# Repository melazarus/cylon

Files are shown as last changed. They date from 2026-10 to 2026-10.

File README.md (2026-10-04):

# Cylon

> A tiny open source / open hardware USB notification light — three side-emitting addressable LEDs on a USB-A stick, driven by a CH32X035 RISC-V MCU.

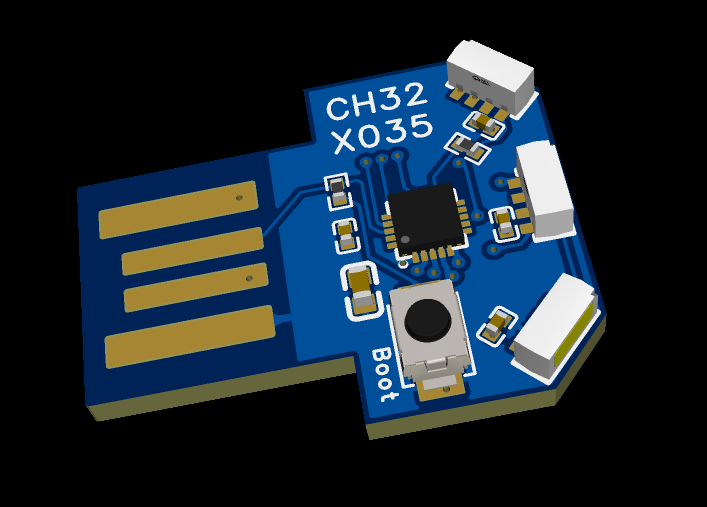
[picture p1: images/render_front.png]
Cylon board render


Cylon plugs straight into a USB-A port and gives you a programmable RGB indicator for build status, notifications, alerts, ambient lighting, etc. It is designed to be cheap, hackable, and easy to manufacture — the USB-A plug is formed by the PCB's own gold-finger edge connector, so there is no connector to solder.

The board speaks class-compliant **USB-MIDI**: the host drives everything with SysEx messages, so no driver is required and any MIDI-capable tool or browser can control it. Firmware can be updated over USB through the factory ROM bootloader.

## Features

- **USB-A PCB plug** — no cable or enclosure required, plugs directly into a host port.
- **CH32X035F8U6** — WCH RISC-V MCU in a small WQFN-20 package, with native USB 2.0 Full-Speed.
- **3× side-emitting WS2812B** (`XL-4020RGBC-2812B`) — individually addressable RGB, arranged so light spills out sideways/around the board. (Note: the mechanical strength of these LEDs is not ideal; a small amount of super glue, or different LEDs, improves it.)
- **USB bootloader + SWD** — flash over USB or via a WCH-LinkE / SWD probe.
- **Boot button** — hold it while plugging in to enter the ROM bootloader; a MIDI command can also reboot into it without touching the board.
- **4 spare GPIOs** — `PA0`–`PA3`, each usable as a push-pull output, a 20 kHz PWM output, or a 50 Hz RC servo output.
- **Minimal BOM** — just 7 components to order, all available from LCSC.
- **Open hardware** — full EasyEDA Pro project, schematic, PCB, Gerbers, and 3D model included.

## Hardware

| | |
|---|---|
| **MCU** | WCH CH32X035F8U6 (RISC-V, WQFN-20) |
| **USB** | USB 2.0 Full-Speed device (USB-A male PCB plug) |
| **LEDs** | 3× XL-4020RGBC-2812B (WS2812B-compatible, side-emitting) |
| **LED data** | `PB1` (`TIM1_CH3N`) → LED1 `DIN`, chained LED1 → LED2 → LED3 |
| **USB D+/D−** | `PC17` (`UDP`) / `PC16` (`UDM`) |
| **Debug** | SWD on `PC18` (`DIO`) / `PC19` (`DCK`) |
| **Boot** | `TS-1088-AR02016` tact switch + 5.1 kΩ resistor to `PC17` |
| **Power** | 5 V from USB, 10 µF bulk + 100 nF decoupling per LED/MCU |
| **Board** | 2-layer, ~23 × 19 mm (incl. USB plug tab), EasyEDA Pro, rev V1.0 |

### Pinout

| Signal | CH32X035 pin |
|---|---|
| WS2812 data out | `PB1` |
| USB `D+` | `PC17` (`UDP`) |
| USB `D−` | `PC16` (`UDM`) |
| SWD `DIO` | `PC18` |
| SWD `DCK` | `PC19` |
| PAD0 | `PA0` |
| PAD1 | `PA1` |
| PAD2 | `PA2` |
| PAD3 | `PA3` |
| `5V0` | `VDD` |
| `GND` | `GND` / EP |

> The WS2812 data line (`PB1`) feeds the first LED through a 100 Ω series resistor; each LED's `DO` feeds the next LED's `DI`, so all three are driven from a single GPIO.

### USB identity

| Field | Value |
|---|---|
| VID / PID | `0x16C0` / `0x27DD` |
| Manufacturer | `AREA3001` |
| Product | `CYLON` |
| Serial | `MD` + 6 hex chars of firmware version + 24 hex chars of the MCU UID |

Every board gets a unique serial number from its 96-bit chip UID; the version prefix also encodes which firmware it is running.

## Protocol

The device is a class-compliant **USB-MIDI** device that listens on **MIDI channel 0**. Control uses **System Exclusive (SysEx)** messages with the tag `13 37`:

```
F0 13 37 <record> ... F7          record = <address> <b1> <b2> <b3>
```

A message may contain any number of 4-byte records; the last write wins. Every payload byte is a **7-bit MIDI data byte** (`0x00`–`0x7F`).

| Address | Target | b1 / b2 / b3 |
| --- | --- | --- |
| `0x00` | all LEDs | r, g, b |
| `0x01`–`0x03` | LED 0/1/2 | r, g, b |
| `0x04`–`0x0A` | animation | base colour (wheels ignore it) |
| `0x0B` | firmware version reply (device → host) | major, minor, patch |
| `0x10`–`0x13` | `PA0`–`PA3` | type, level, speed/ignored |
| `0x7F` | command | cmd, arg0, arg1 |

Unused/reserved addresses are ignored. The full protocol and the memory map live in [`docs/PROTOCOL.md`](docs/PROTOCOL.md).

### Static colours

```
F0 13 37 <led> <r> <g> <b> F7          led = 0x00 (all) or 0x01..0x03
```

`r`/`g`/`b` are 7-bit; the firmware shifts them left by one, so the LED receives an **even** 8-bit value and `0x7F` is the maximum (`0xFE`). Setting a static colour stops any running animation.

### Animations

Addresses `0x04`–`0x0A` start an on-device animation using the same record shape (the three colour bytes are the base colour):

| Address | Animation |
| --- | --- |
| `0x04` | blink at 1 Hz |
| `0x05` | blink at 2 Hz |
| `0x06` | breathe at 1 Hz |
| `0x07` | breathe at 2 Hz |
| `0x08` | Larson scanner (the moving dot) |
| `0x09` | colour wheel, one hue offset per LED |
| `0x0A` | colour wheel, all LEDs the same hue |

Animations are rendered on-device at 50 Hz; the host sends the record once.

### Auxiliary pins

`0x10`–`0x13` map to `PA0`–`PA3` (`TIM2_CH1..CH4`):

| Byte | Meaning |
| ---- | --- |
| `<type>` | `0x00` push-pull output, `0x01` PWM output, `0x02` servo output |
| `<level>` | push-pull: `0x00` low / `0x01` high<br>PWM: `0x00` = 0 % … `0x7F` = 100 % duty<br>servo: `0x00` = 0 % … `0x7F` = 100 % position |
| `<extra>` | push-pull / PWM: ignored<br>servo: move time — `0x00` instant, `0x01`–`0x7F` = 100 ms … 12.7 s |

A pin stays an input until its first record and can switch modes at any time. Pins are independent of the LEDs and do not stop a running animation. PWM runs at 20 kHz; a servo uses a 50 Hz frame with a 0.5–2.5 ms pulse (narrow it with command `0x10` if the servo over-drives) and sweeps to the new position over the move time. Because `PA0`–`PA3` share one timer, PWM reverts to 50 Hz while any servo is active.

### Commands

Address `0x7F` is a command record `<0x7F> <cmd> <arg0> <arg1>`:

| Command | Meaning |
| --- | --- |
| `0x01` | reboot into the ROM USB bootloader |
| `0x02` | request firmware version |
| `0x10` | set the servo pulse range (`arg0` = min, `arg1` = max, 20 µs units) |

Command `0x02` makes the device reply over the USB-MIDI IN endpoint with a normal record:

```
F0 13 37 0B <major> <minor> <patch> F7
```

For firmware `1.0.0` that is `F0 13 37 0B 01 00 00 F7`. Unknown commands and non-zero arguments are ignored.

### Examples

```
LED 0 red              F0 13 37 01 7F 00 00 F7
All LEDs green         F0 13 37 00 00 7F 00 F7
LED0 red, LED2 blue    F0 13 37 01 7F 00 00 03 00 00 7F F7
Larson scanner, cyan   F0 13 37 08 00 7F 7F F7
Colour wheel (offset)  F0 13 37 09 00 00 00 F7
PA0 high               F0 13 37 10 00 01 00 F7
PA1 PWM 50%            F0 13 37 11 01 40 00 F7
PA2 servo 50%, 1 s     F0 13 37 12 02 40 0A F7
Reboot to bootloader   F0 13 37 7F 01 00 00 F7
Request firmware ver.  F0 13 37 7F 02 00 00 F7
```

## Firmware

The PlatformIO project lives in [`firmware/`](firmware), with a small vendored USB-MIDI stack in `firmware/lib/CH32X035_USB_MIDI`.

See [`docs/BUILD.md`](docs/BUILD.md) for the full build, versioning and release process.

| File | Responsibility |
| ---- | --- |
| `main.c` | boot sequence, then `midi_run()` |
| `board.c/.h` | WS2812 driver (`TIM1_CH3N` + DMA1 ch5) and LED state |
| `midi.c/.h` | SysEx parsing, address map, commands |
| `anim.c/.h` | animation engine (free-running `TIM3` time base) |
| `pins.c/.h` | auxiliary `PA0`–`PA3` GPIO / 20 kHz PWM (`TIM2`) |
| `debug.c/.h` | delays and optional `printf` retargeting |

The WS2812 waveform is generated entirely in hardware: **TIM1** runs at 48 MHz with `ARR = 59` (1.25 µs per bit), **DMA1 channel 5** writes one compare value per bit to `TIM1_CH3N`, and the compare value *is* the bit's high time. On boot the firmware starts the LED driver and runs a ~3 s startup colour ramp that ends on LED 0 red, LED 1 green, LED 2 blue; it then brings up USB and enters the MIDI loop.

### Building

Prerequisites: [PlatformIO](https://platformio.org) and the [Community CH32V platform](https://github.com/Community-PIO-CH32V/platform-ch32v).

```bash
pip install platformio
pio pkg install -g -p "https://github.com/Community-PIO-CH32V/platform-ch32v.git#8cf3b51c0ee537756a04c28336f1466e03424020"

cd firmware
pio run -e release      # optimised, no logging
pio run -e debug        # -Og -g3 with serial logging on USART1 (PB10, 115200)
```

The platform is pinned to a commit so builds are reproducible. The output binary is `firmware/.pio/build/<env>/firmware.bin`. The firmware version comes from the `CYLON_VERSION` environment variable (e.g. a tag `v1.0.0`) and falls back to `1.0.0`; it is reported over USB-MIDI (command `0x02`) and encoded in the USB serial number.

### Flashing

`firmware/platformio.ini` sets `upload_protocol = isp`, so PlatformIO uses its bundled [`wchisp`](https://github.com/ch32-rs/wchisp):

```bash
cd firmware
pio run -e release -t upload
```

Put the board into the ROM bootloader first — **unplug USB, hold BOOT, plug USB back in**. The BOOT button pulls `PC17` (the boot-detection pin, which doubles as USB `D+`) high at power-up; the pin is sampled only once, on reset. The bootloader enumerates as a WCH ISP device (`4348:55e0` / `1a86:55e0`).

You can skip the button by asking a running board to reboot into the bootloader over MIDI:

```bash
uv run tools/set_leds.py --boot
cd firmware && pio run -e release -t upload
```

SWD (`PC18`/`PC19`) is the button-free alternative and does not depend on the boot strap. On Windows you may need to bind the bootloader to WinUSB with [Zadig](https://zadig.akeo.ie/). On Linux, grant access with a udev rule and reload it:

```
# /etc/udev/rules.d/60-wchisp.rules
SUBSYSTEM=="usb", ATTR{idVendor}=="4348", ATTR{idProduct}=="55e0", MODE="0666"
SUBSYSTEM=="usb", ATTR{idVendor}=="1a86", ATTR{idProduct}=="55e0", MODE="0666"
```

```bash
sudo udevadm control --reload-rules && sudo udevadm trigger
# replug the board and restart the browser
```

### Releases

Pushing a `v<major>.<minor>.<patch>` tag runs [`.github/workflows/release.yml`](.github/workflows/release.yml): it builds the `release` environment with `CYLON_VERSION` set from the tag and attaches `firmware.bin` and `cylon-<tag>.bin` to a **draft** GitHub release. Publish the draft to make the version available to the web tool's updater.

## Web control & firmware update

[`public/`](public) is a responsive static page (published to GitHub Pages) for controlling the board from a Chromium browser:

- LED colours and animations, the four I/O pins, and the live firmware version;
- firmware updates over USB — it lists versions from this repository's GitHub releases, can reboot the board into the bootloader, and flashes over WebUSB.

It uses **Web MIDI** for control and **WebUSB** for flashing, so it needs Chrome or Edge (desktop or Android) over HTTPS. Once deployed it is at `https://melazarus.github.io/cylon/`; the Pages workflow is [`.github/workflows/pages.yml`](.github/workflows/pages.yml) and the repository's Pages source must be set to **GitHub Actions**.

## Command-line tool

[`tools/set_leds.py`](tools/set_leds.py) is a [uv](https://docs.astral.sh/uv/) / PEP 723 script (it pulls in `pygame` for its MIDI backend):

```bash
uv run tools/set_leds.py 0 ff0000     # LED 0 red
uv run tools/set_leds.py all ffffff   # all LEDs white
uv run tools/set_leds.py 0 red        # named colours
uv run tools/set_leds.py --pin 1 --pwm 64                 # PA1 PWM, 50 %
uv run tools/set_leds.py --pin 2 --servo 64 --speed 10    # PA2 servo 50 %, 1 s move
uv run tools/set_leds.py --servo-range 500 2260           # narrow the servo pulse range
uv run tools/set_leds.py --list       # list MIDI output ports
uv run tools/set_leds.py --boot       # reboot into the ROM bootloader
uv run tools/set_leds.py --version    # read the firmware version
```

Named colours: `off`, `black`, `red`, `green`, `blue`, `white`, `yellow`, `cyan`, `magenta`, `orange`, `purple`, `pink`. The port is auto-detected by matching `"cylon"`; use `--port` if your system names it differently.

## Repository layout

```
.
├── .github/workflows/        # GitHub Pages deploy + tagged firmware releases
├── docs/
│   ├── BUILD.md              # build, versioning & release guide
│   └── PROTOCOL.md           # USB-MIDI protocol reference
├── firmware/                 # PlatformIO firmware (CH32X035) + version.py
├── hardware/                 # EasyEDA Pro project, schematic, PCB, gerbers, BOM, 3D
├── images/
│   └── render_front.png      # Board render
├── public/                   # Static web tool (deployed to GitHub Pages)
├── tools/                    # Python CLI
├── LICENSE
└── README.md
```

## Contributing

Issues, pull requests, and hardware/firmware forks are all welcome. If you build one, share a photo!

## License

Released under the [MIT License](LICENSE). © 2026 Hans Polders.

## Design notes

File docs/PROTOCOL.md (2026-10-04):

# Cylon — protocol & memory map

Reference for the wire protocol and the CH32X035 memory layout used by the
firmware. Source of truth is the code: `firmware/src/midi.c` (protocol),
`board.c`, `anim.c`, `pins.c`, and the PlatformIO SDK headers for the addresses.

---

# Part 1 — USB-MIDI protocol

## 1.1 Transport

- Class-compliant **USB-MIDI** device (no host driver).
- The device listens on **MIDI channel 0** only.
- The device also has a **USB-MIDI IN** endpoint. Command replies (currently
  only the firmware version) are sent back as SysEx, so a host that wants a
  reply must open the matching MIDI input as well as the output.
- **System Exclusive (SysEx)** — full control: static colours, animations,
  auxiliary pins, commands.
- Every byte in a SysEx payload is a **7-bit MIDI data byte** (`0x00`–`0x7F`).

## 1.2 SysEx framing

```
F0 13 37 [ <record> ] ... F7
```

| Byte | Meaning |
| ---- | --- |
| `F0` | SysEx start |
| `13 37` | protocol tag (a chosen marker, **not** a registered manufacturer ID) |
| records | one or more 4-byte records (below) |
| `F7` | SysEx end |

A single message may carry any number of records; they are applied in order and
the last write wins. The parser also accepts a message split across several
USB-MIDI packets and all four SysEx Code Index Numbers (`0x04`–`0x07`).

## 1.3 Records and the address map

Each record is `<address> <b1> <b2> <b3>` — four 7-bit bytes. The first byte
selects what the record does:

| Address | Target | b1 | b2 | b3 |
| --- | --- | -- | -- | -- |
| `0x00` | all LEDs | r | g | b |
| `0x01`–`0x03` | LED 0/1/2 | r | g | b |
| `0x04`–`0x0A` | animation | see §1.5 | | |
| `0x0B` | firmware version reply (device → host) | major | minor | patch |
| `0x0C`–`0x0F` | *reserved* | | | |
| `0x10`–`0x13` | pin PA0–PA3 | type | level | speed / ignored |
| `0x14`–`0x7E` | *reserved* | | | |
| `0x7F` | command | cmd | arg0 | arg1 |

Unused/reserved addresses are ignored.

## 1.4 Static LED colour

```
<led> <r> <g> <b>          led = 0x00 (all) or 0x01..0x03
```

`r`/`g`/`b` are 7-bit; the firmware shifts them left by one, so the LED receives
an **even** 8-bit value and `0x7F` is the maximum (`0xFE`). Setting a static
colour **stops any running animation**.

## 1.5 Animations

Addresses `0x04`–`0x0A` start an animation. The three colour bytes are the base
colour for the first four and the scanner; the colour wheels ignore them.

| Address | Animation | Colour bytes |
| --- | --- | --- |
| `0x04` | blink at 1 Hz | base colour |
| `0x05` | blink at 2 Hz | base colour |
| `0x06` | breathe at 1 Hz | base colour |
| `0x07` | breathe at 2 Hz | base colour |
| `0x08` | Larson scanner (the moving dot) | base colour |
| `0x09` | colour wheel, one hue offset per LED | ignored |
| `0x0A` | colour wheel, all LEDs same hue | ignored |

Animations are rendered on-device at 50 Hz. Any static colour record (§1.4) stops the running animation.

## 1.6 Auxiliary pins

Addresses `0x10`–`0x13` map to **PA0–PA3**:

| Byte | Meaning |
| ---- | --- |
| `<type>` | `0x00` push-pull output, `0x01` PWM output, `0x02` servo output |
| `<level>` | push-pull: `0x00` low / `0x01` high<br>PWM: `0x00` = 0 % … `0x7F` = 100 % duty<br>servo: `0x00` = 0 % … `0x7F` = 100 % position |
| `<extra>` | push-pull / PWM: ignored<br>servo: move time — `0x00` = instant, `0x01`–`0x7F` = 100 ms … 12.7 s |

A pin stays an input until its first record and can switch between modes at any
time. Pins are independent of the LEDs and do **not** stop a running animation.

- **PWM** runs at 20 kHz.
- **Servo** drives a standard RC servo: a 50 Hz frame with a 0.5 ms (0 %) to
  2.5 ms (100 %) pulse (configurable with command `0x10`). A non-zero move time
  sweeps the position linearly from where it is now to the new target.
- PA0–PA3 are the four channels of **one timer** (`TIM2`), so PWM (20 kHz) and
  servo (50 Hz) cannot run at once: while at least one servo is active the
  timer runs at 50 Hz and any PWM pin is also 50 Hz (its duty is unchanged).

## 1.7 Commands

Address `0x7F` is a command record `<0x7F> <cmd> <arg0> <arg1>`:

| Command | Meaning | 
| --- | --- |
| `0x01` | reboot into the ROM USB bootloader |
| `0x02` | request firmware version (reply: record `0x0B`) |
| `0x10` | set the servo pulse range (`arg0` = min, `arg1` = max, 20 µs units) |

Unknown commands and non-zero arguments are ignored.

Command `0x02` asks the device to answer over the USB-MIDI IN endpoint with a
normal four-byte record so the host can reuse its record parser:

```
F0 13 37 0B <major> <minor> <patch> F7
```

Each component is a 7-bit number. The current firmware is `1.0.0`, so the
reply is `F0 13 37 0B 01 00 00 F7`. The device answers once per matching `0x02`
record; `arg0` and `arg1` must be zero, like every other command.

Command `0x10` sets the pulse range used by servo pins (type `0x02`). Both
arguments are in **20 µs units** (`0x00`–`0x7F` = 0–2540 µs); the default is
`0x19` (25 → 500 µs) to `0x7D` (125 → 2500 µs). Narrow it if a servo reaches
its mechanical limit before 100 %: a servo that buzzes above ≈2.26 ms can be
limited to `F0 13 37 7F 10 19 71 F7` (500–2260 µs), after which position `0x7F`
is that maximum instead of over-driving the servo. The setting is runtime only
and applies to every servo pin.

## 1.8 Interaction rules

- A **static colour** (SysEx `0x00`–`0x03`) **stops** any running
  animation and holds that colour.
- An **animation** starts (or replaces) the running animation.
- **Pins** never affect the LEDs and never stop an animation.

## 1.9 Examples

```
LED 0 red              F0 13 37 01 7F 00 00 F7
All LEDs green         F0 13 37 00 00 7F 00 F7
LED0 red, LED2 blue    F0 13 37 01 7F 00 00 03 00 00 7F F7
Larson scanner, cyan   F0 13 37 08 00 7F 7F F7
Colour wheel (offset)  F0 13 37 09 00 00 00 F7
PA0 high               F0 13 37 10 00 01 00 F7
PA1 PWM 50%            F0 13 37 11 01 40 00 F7
PA2 servo 50%, 1 s     F0 13 37 12 02 40 0A F7
Reboot to bootloader   F0 13 37 7F 01 00 00 F7
Request firmware ver.  F0 13 37 7F 02 00 00 F7
Version reply (1.0.0)  F0 13 37 0B 01 00 00 F7   (device → host)
```

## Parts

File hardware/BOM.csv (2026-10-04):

No. | Quantity | Comment | Designator | Footprint | Value | Manufacturer Part | Manufacturer | Supplier Part | Supplier
1 | 1 | TS-1088-AR02016 | Boot | SW-SMD_L3.9-W3.0-P4.45 |  | TS-1088-AR02016 | XUNPU(讯普) | C720477 | LCSC
2 | 4 | 100nF | C1,C2,C3,C4 | C0402 | 100nF | CL05B104KO5NNNC | SAMSUNG(三星) | C1525 | LCSC
3 | 1 | 10uF | C5 | C0603 | 10uF | CL10A106KP8NNNC | SAMSUNG(三星) | C19702 | LCSC
4 | 3 | XL-4020RGBC-2812B | LED1,LED2,LED3 | LED-SMD_4P-L4.0-W1.7_XL-4020RGBC-WS2812B |  | XL-4020RGBC-2812B | XINGLIGHT(成兴光) | C3647024 | LCSC
5 | 1 | 5.1kΩ | R1 | R0402 | 5.1kΩ | FRC0402J512 TS | FOJAN(富捷) | C2906948 | LCSC
6 | 1 | 100Ω | R2 | R0402 | 100Ω | 0402WGF1000TCE | UNI-ROYAL(厚声) | C25076 | LCSC
7 | 1 | USB-A-PCB | U1 | USB-A-PCB
8 | 1 | CH32X035F8U6 | U2 | WQFN-20_L3.0-W3.0-P0.40-TL-EP1.7 |  | CH32X035F8U6 | WCH(南京沁恒) | C42442062 | LCSC

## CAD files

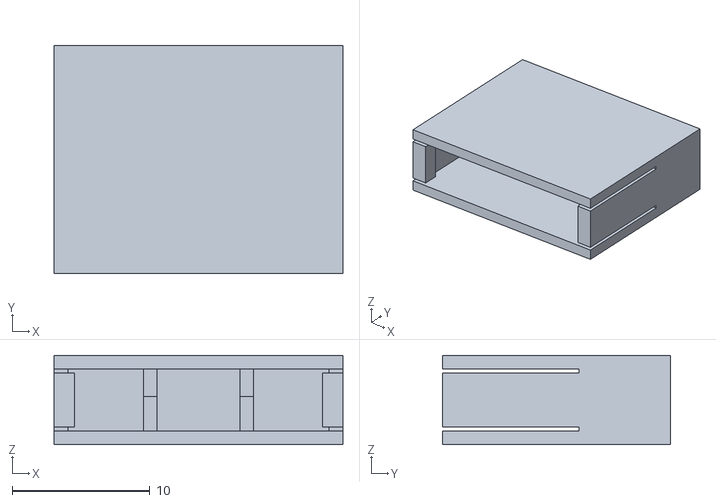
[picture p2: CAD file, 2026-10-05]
case/cover.stl
21.0 x 16.6 x 6.50

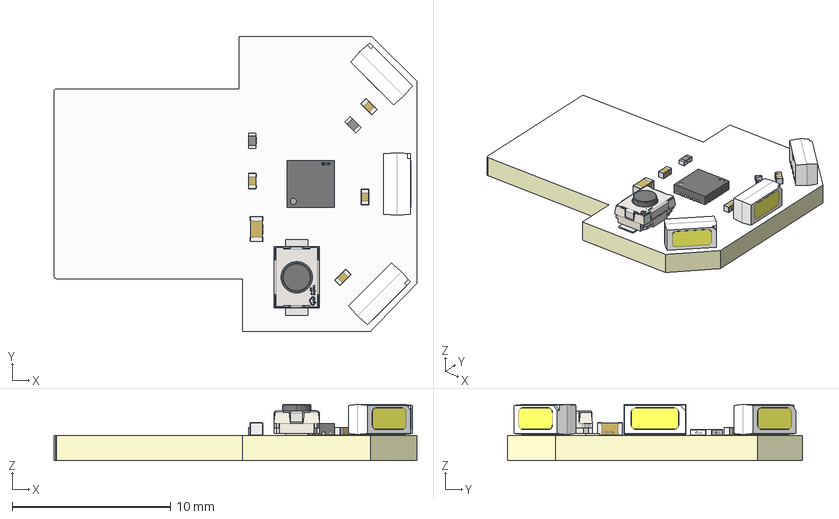
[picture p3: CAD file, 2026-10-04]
hardware/3D.step
23.0 x 18.6 x 3.55 mm
Board~OXDE
TopCopper~OXDE
BottomCopper~OXDE
TopSilkscreen~OXDE
BottomSilkscreen~OXDE
TopFpcStiffener~OXDE
BottomFpcStiffener~OXDE
C0402~C0402_L1.0-W0.5-H0.5~OXDE x 4
R0402~R0402_L1.0-W0.5-H0.4~OXDE x 2
C0603~C0603_L1.6-W0.8-H0.8~OXDE
SW-SMD_L3.9-W3.0-P4.45~SW-SMD_L3.9-W2.9-H2.0-LS4.8~OXDE
LED-SMD_4P-L4.0-W1.7_XL-4020RGBC-WS2812B~LED-SMD_4P-L4.0-W1.7_ XL-4020RGBC-WS2812B~OXDE x 3
WQFN-20_L3.0-W3.0-P0.40-TL-EP1.7~WQFN-20_ L3.0-W3.0-H0.8-P0.40-TL-EP1.7~OXDE

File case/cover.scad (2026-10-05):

/* Cylon cover — slide-on shell for the board.
 *
 * The board enters from the open front (Y = 0) and butts against the back
 * wall. Two shallow grooves at the top and bottom of the cavity act as
 * retention lips, and the small posts at the front corners locate the board.
 *
 * Everything below is parametric; the defaults reproduce the original part.
 * Dimensions are in millimetres. Each parameter group has a section comment so
 * it shows up grouped in OpenSCAD's Customizer.
 */

/* [Board] */
board_w   = 19;    // board width (X)
board_d   = 16;    // board depth that slides into the cover (Y)
board_h   = 4.5;   // board + tallest component (Z)

/* [Shell] */
wall      = 1;     // side, floor and roof thickness
back_wall = 0.6;   // material left behind the board

/* [Retention grooves] */
groove_h     = 0.3; // groove height (Z)
groove_inset = 6;   // how far the groove stops short of the back (Y)
cut          = 0.05; // overcut so the groove clears the side walls

/* [Back clips] */
clip_w     = 1;    // clip width (X)
clip_d     = 4;    // clip depth (Y)
clip_inset = 4;    // clip front face offset from the outer back (Y)
tab_h      = 3.5;  // short tab height (Z)
tab_d      = 6;    // short tab depth (Y)

/* [Front posts] */
post   = 1.5;         // post cross-section (X/Y)
post_h = 3.9;         // post height (Z)
post_z = wall + 0.3;  // post base height (Z)

/* [Hidden] */
outer_w = board_w + 2 * wall;  // overall width
outer_d = board_d + back_wall; // overall depth
outer_h = board_h + 2 * wall;  // overall height

// --------------------------------------------------------------- modules

// Hollow shell: open at the front, closed at the back, with both grooves.
module shell() {
    difference() {
        cube([outer_w, outer_d, outer_h]);

        // board cavity (the extra `cut` keeps the back wall exactly back_wall deep)
        translate([wall, -cut, wall])
            cube([board_w, board_d + cut, board_h]);

        // retention grooves at the floor and roof of the cavity
        for (z = [wall, wall + board_h - groove_h])
            translate([-cut, -cut, z])
                cube([outer_w + 2 * cut, board_d - groove_inset, groove_h]);
    }
}

// Back clips: two full-height clips plus two shorter locating tabs.
module clips() {
    for (x = [outer_w / 3, outer_w * 2 / 3]) {
        translate([x - clip_w / 2, outer_d - clip_inset, 0])
            cube([clip_w, clip_d, outer_h]);
        translate([x - clip_w / 2, outer_d - tab_d, 0])
            cube([clip_w, tab_d, tab_h]);
    }
}

// Front corner posts that locate the board.
module posts() {
    for (x = [0, outer_w - post])
        translate([x, 0, post_z])
            cube([post, post, post_h]);
}

// --------------------------------------------------------------- assembly

union() {
    shell();
    clips();
    posts();
}

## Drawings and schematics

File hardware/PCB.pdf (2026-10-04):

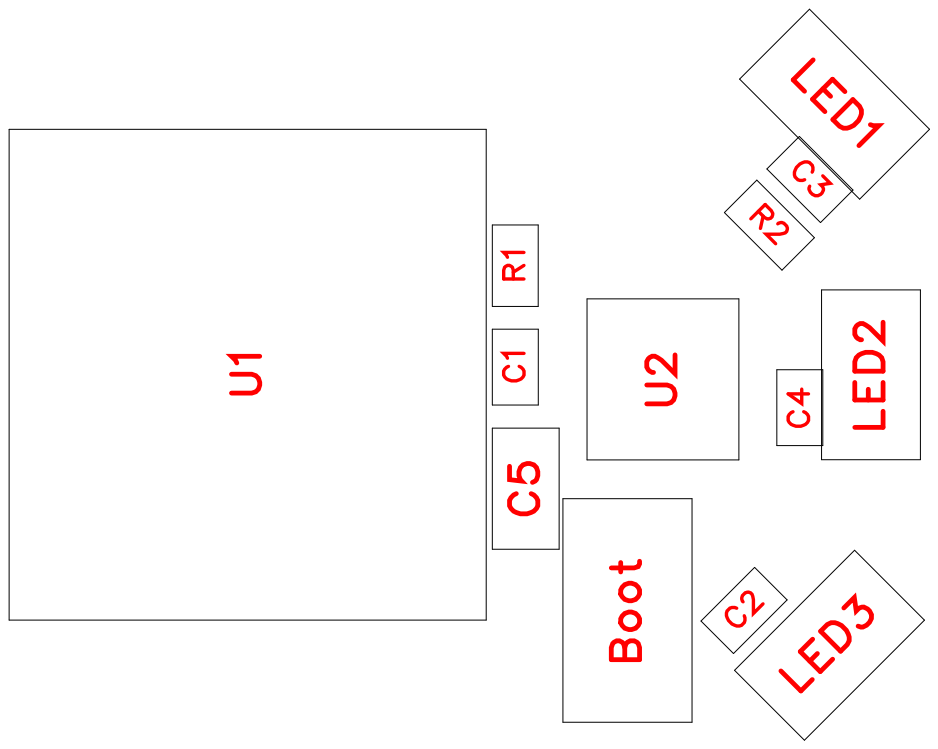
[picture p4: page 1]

No. | Quantity | Comment | Designator | Footprint | Value | Manufacturer Part | Manufacturer | Supplier Part | Supplier
1 | 1 | TS-1088-AR 02016 | Boot | SW-SMD_L3 .9-W3.0-P4.4 5 | | TS-1088-AR 02016 | XUNPU(讯普 ) | C720477 | LCSC
2 | 4 | 100nF | C1,C2,C3,C4 | C0402 | 100nF | CL05B104K O5NNNC | SAMSUNG( ) 三星 | C1525 | LCSC
3 | 1 | 10uF | C5 | C0603 | 10uF | CL10A106KP 8NNNC | SAMSUNG( ) 三星 | C19702 | LCSC
4 | 3 | XL-4020RGB C-2812B | LED1,LED2,LED3 | LED-SMD_4 P-L4.0-W1.7 _XL-4020RG BC-WS2812 B | | XL-4020RGB C-2812B | XINGLIGHT( 成兴光 ) | C3647024 | LCSC
5 | 1 | 5.1k | R1 | R0402 | 5.1k | FRC0402J51 2 TS | FOJAN(富捷 ) | C2906948 | LCSC
6 | 1 | 100 | R2 | R0402 | 100 | 0402WGF10 00TCE | UNI-ROYAL( 厚声 ) | C25076 | LCSC
7 | 1 | USB-A-PCB | U1 | USB-A-PCB
8 | 1 | CH32X035F8 U6 | U2 | WQFN-20_L 3.0-W3.0-P0. 40-TL-EP1.7 | | CH32X035F8 U6 | WCH(南京沁 恒) | C42442062 | LCSC

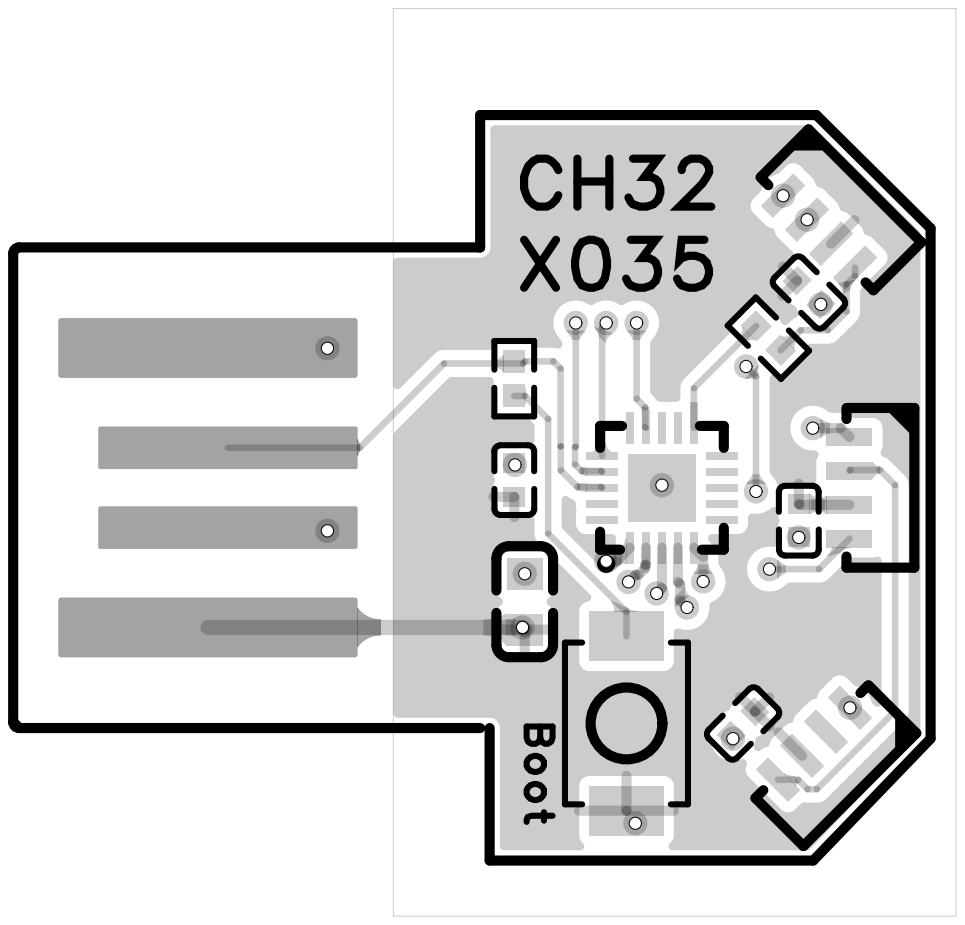
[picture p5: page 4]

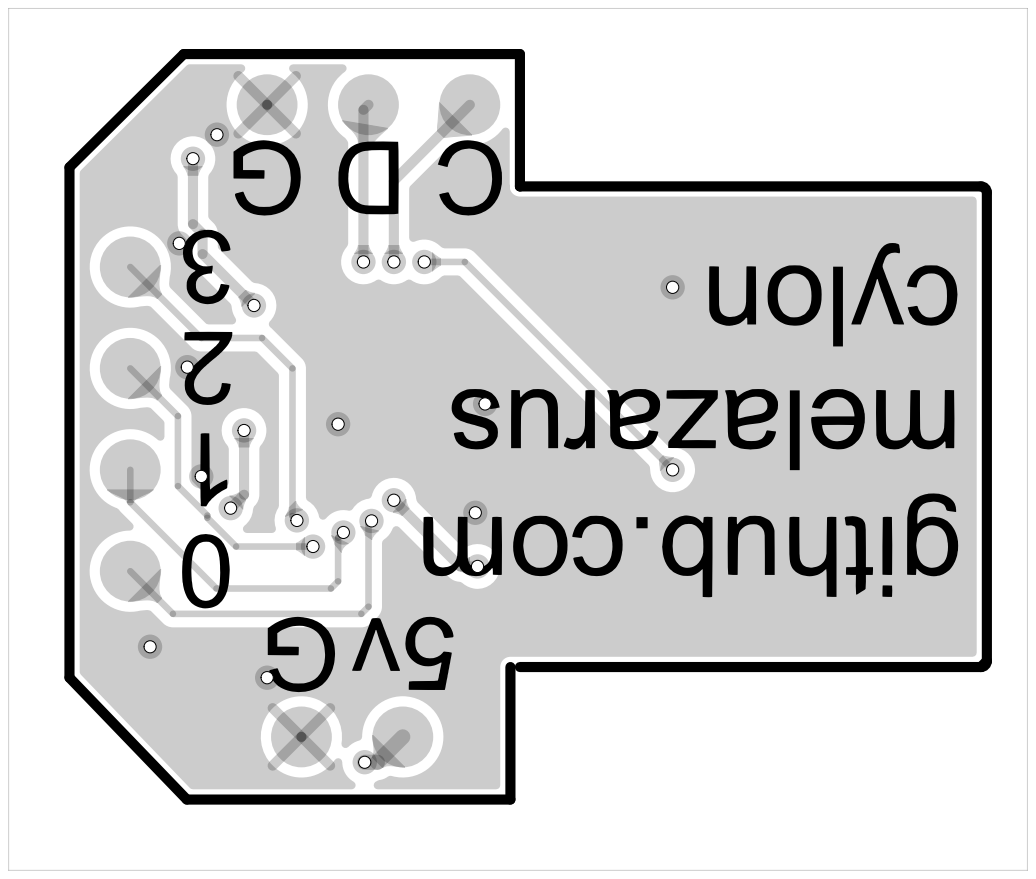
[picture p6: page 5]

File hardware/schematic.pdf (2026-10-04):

Power | MCU - CH32X035

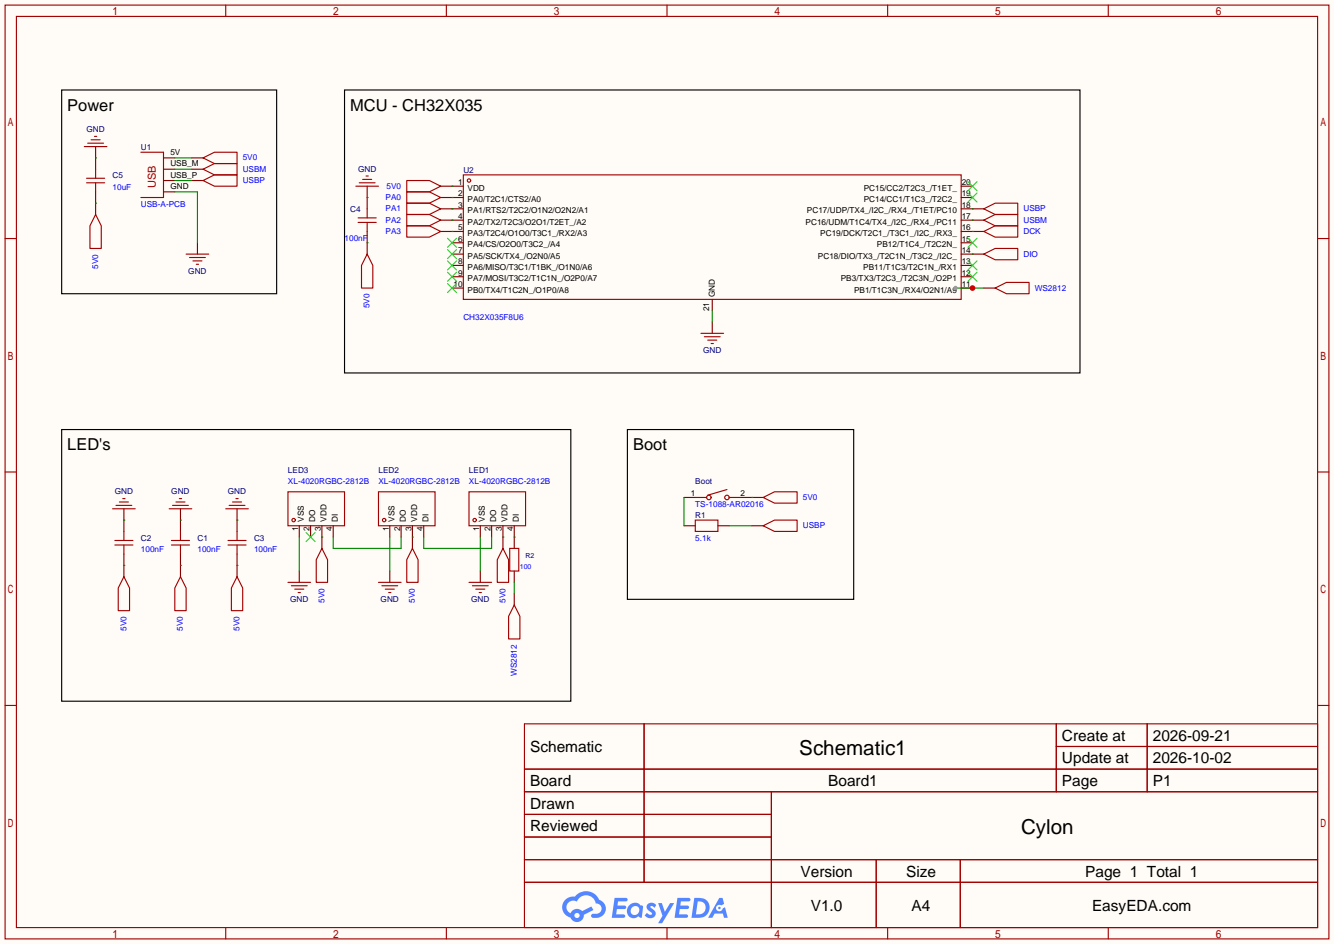
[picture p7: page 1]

Schematic | Schematic1 | Create at | 2026-09-21

Update at | 2026-10-02

Board | Board1 | Page | P1
Drawn | | Cylon
Reviewed

Version | Size | Page 1 Total 1
V1.0 | A4 | EasyEDA.com

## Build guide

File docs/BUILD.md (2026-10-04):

# Building, versioning & releasing

How to build the Cylon firmware, choose a version number, and cut a release.
The wire protocol is documented separately in [`PROTOCOL.md`](PROTOCOL.md).

## Lifecycle at a glance

```
local   pio run -e release         -> firmware/.pio/build/release/firmware.bin
tag     git tag v1.1.0 && push     -> .github/workflows/release.yml
CI      build with CYLON_VERSION   -> draft release: firmware.bin, cylon-v1.1.0.bin
publish click "Publish release"    -> .github/workflows/pages.yml bundles the binary
site    version selector           -> WebUSB flash
```

## Prerequisites

- [PlatformIO](https://platformio.org) (the CLI is enough)
- The [Community CH32V platform](https://github.com/Community-PIO-CH32V/platform-ch32v), pinned to a known commit:

```bash
pip install platformio
pio pkg install -g -p "https://github.com/Community-PIO-CH32V/platform-ch32v.git#8cf3b51c0ee537756a04c28336f1466e03424020"
```

The pin (also used by the release workflow) makes builds reproducible. The first
build downloads the WCH none-OS SDK and the RISC-V toolchain, so it takes a
while; later builds are fast.

## Environments

`firmware/platformio.ini` defines two environments:

| Environment | Flags | Notes |
| --- | ----- | ----- |
| `debug` | `-DDEBUG=1 -Og -g3 -Wall -Wextra` | serial logging on `USART1` (`PB10`, 115200 8N1) |
| `release` | `-DDEBUG=0 -Os -Wall -Wextra` | drops logging and newlib `printf`; the environment CI builds |

Both must build **warning-free**. The output is
`firmware/.pio/build/<env>/firmware.bin`.

## The firmware version

The version is injected at build time by [`firmware/version.py`](../firmware/version.py)
(a PlatformIO pre-script):

- It reads **`CYLON_VERSION`** from the environment (the release workflow passes
  the git tag, e.g. `v1.1.0`).
- If unset, it falls back to **`DEFAULT_VERSION`** (`1.0.0`).
- It accepts `v<major>.<minor>.<patch>` (the `v` is optional). Anything that
  isn't semver prints a warning and falls back to the default.
- It defines the `VERSION_MAJOR` / `VERSION_MINOR` / `VERSION_PATCH` macros used
  by the USB-MIDI library (USB serial number) and by `midi.c` (the `0x02`
  version reply).

Bump `DEFAULT_VERSION` when you release, so a plain local build reports the same
version as the release. CI overrides it from the tag, so the tag is the single
source of truth for released firmware.

```bash
# local build reporting a specific version
CYLON_VERSION=v1.1.0 pio run -e release
```

### Where the version appears

| Place | Format | Example for `1.1.0` |
| ----- | --- | --- |
| USB serial number | `MD` + 6 hex chars + 24 hex UID | `MD010100…` |
| USB-MIDI `0x02` reply (record `0x0B`) | `F0 13 37 0B <major> <minor> <patch> F7` | `F0 13 37 0B 01 01 00 F7` |
| Release asset | `cylon-<tag>.bin` | `cylon-v1.1.0.bin` |

## Building

```bash
cd firmware
pio run -e release      # or: pio run -e debug
```

## Flashing

See the README's [Flashing](../README.md#flashing) section for the full detail.
In short:

- **USB ISP (normal):** put the board in the ROM bootloader — unplug USB, hold
  BOOT, plug back in — then `pio run -e release -t upload`. The bootloader
  enumerates as `4348:55e0` / `1a86:55e0`.
- **Without the button:** `uv run tools/set_leds.py --boot` (or the web tool's
  checkbox) reboots a running board into the bootloader over MIDI.
- **SWD:** `PC18`/`PC19` via a WCH-LinkE, always available and independent of
  the boot strap.
- **Browser:** the `public/` web tool flashes over WebUSB. On Windows bind the
  bootloader to WinUSB with [Zadig](https://zadig.akeo.ie/); on Linux add the
  udev rule (see the README).

## Versioning

Cylon follows [Semantic Versioning](https://semver.org/): `MAJOR.MINOR.PATCH`.

| Change | Bump | Example |
| --- | ---- | --- |
| **New, backwards-compatible feature** | **MINOR** | `1.0.0 → 1.1.0` — a new animation, command, pin mode |
| **Bug fix only** (no new functionality) | **PATCH** | `1.0.0 → 1.0.1` — fix flicker, correct a colour |
| **Breaking change** to the protocol or behaviour | **MAJOR** | `1.0.0 → 2.0.0` — change an existing record's meaning, remove an address |

Rules of thumb:

- Adding a new command or a new address/record is **MINOR** — existing tools
  keep working.
- Changing what an existing address or command *does*, or removing one, is
  **MAJOR**.
- If a change touches the protocol, update [`PROTOCOL.md`](PROTOCOL.md) in the
  same commit and mention it in the release notes.

## Cutting a release

1. (Optional but tidy) bump `DEFAULT_VERSION` in `firmware/version.py` to the
   new version.
2. Commit and push to `main`.
3. Tag and push:

   ```bash
   git tag -a v1.1.0 -m "Cylon 1.1.0"
   git push origin v1.1.0
   ```

4. [`.github/workflows/release.yml`](../.github/workflows/release.yml) runs:
   installs PlatformIO + the pinned CH32V platform, builds the `release`
   environment with `CYLON_VERSION` set from the tag, and creates a **draft**
   GitHub release with `firmware.bin` and `cylon-<tag>.bin`.
5. Review and **Publish** the draft. Publishing triggers
   [`.github/workflows/pages.yml`](../.github/workflows/pages.yml), which runs
   [`.github/scripts/bundle_firmware.py`](../.github/scripts/bundle_firmware.py)
   to download published release binaries into `public/firmware/` and writes
   `releases.json`; the site's version selector then lists the new version.

Notes:

- Releases are created as **drafts** on purpose — nothing is public (and the
  web updater won't list it) until you publish.
- To re-run a build for the same tag, delete the tag and draft, then re-push:

  ```bash
  git tag -d v1.1.0
  git push origin :refs/tags/v1.1.0
  git tag -a v1.1.0 -m "Cylon 1.1.0"
  git push origin v1.1.0
  ```

- The site serves firmware **same-origin** from `public/firmware/` because
  GitHub's release asset host does not send CORS headers. Don't link the site
  directly at `github.com/…/releases/download/…`.

## Troubleshooting

- **Both environments must build warning-free** (`-Wall -Wextra`); treat warnings
  as errors.
- **Version looks wrong:** check the `Cylon firmware version X.Y.Z` line the
  pre-script prints at the top of the build, and remember a plain local build
  uses `DEFAULT_VERSION`, not the latest tag.
- **Flashed but still the old version:** the board's `0x02` reply and USB serial
  report the *built* version — re-run with the right `CYLON_VERSION`/tag.
- **Firmware update fails:** the device may be left in the bootloader; unplug
  and replug to run the application again, then reflash. A bad flash is always
  recoverable via the BOOT strap or SWD.

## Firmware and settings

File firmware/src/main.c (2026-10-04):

#include <ch32x035.h> /* both X033 and X035 */

#include <wch_usbmidi_internal.h>

#include "anim.h"
#include "board.h"
#include "debug.h"
#include "midi.h"

int main(void)
{
    SystemInit();
#ifdef NVIC_PriorityGroup_2
    NVIC_PriorityGroupConfig(NVIC_PriorityGroup_2);
#else
    NVIC_PriorityGroupConfig(NVIC_PriorityGroup_1);
#endif
    SystemCoreClockUpdate();
    Delay_Init();

#if DEBUG
    /* serial logging for the debug build (USART1 TX = PB10, 115200 8N1) */
    USART_Printf_Init(115200);
#endif

    /* bring up the LED driver and hold the data line low right away; the LEDs
     * show an undefined color until they receive their first valid frame */
    board_init();
    anim_init();

    PRINT("SystemClk: %u\r\n", (unsigned)SystemCoreClock);
    PRINT("ChipID: %08x\r\n", (unsigned)DBGMCU_GetCHIPID());

    
    /* Startup animation, will change in the future when there is a state we can persist.
     */
    for (int i = 0; i < 30; i++)
    {
        board_set_led(0, i*8, 0x00, (29*8)-(i*8));
        board_set_led(1, (29*8)-(i*8), i*8, 0x00);
        board_set_led(2, 0x00, (29*8)-(i*8), i*8);

        board_show_leds();
        Delay_Ms(100);
    }

    USB_init();

    PRINT("Cylon init done\r\n");

    /* USB-MIDI LED controller mode, never returns */
    midi_run();
}

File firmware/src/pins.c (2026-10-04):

/* Auxiliary GPIO / PWM / servo outputs PA0..PA3 for SysEx addresses 0x10..0x13.
 *
 * Type 0x00 drives the pin as a plain push-pull GPIO (level 0 = low, 1 = high).
 * Type 0x01 switches the pin to PWM and uses level as a duty cycle from 0x00
 * (0%) to 0x7F (100%). Type 0x02 drives an RC servo: level is the position
 * (0x00..0x7F = 0..100%) and the extra byte is the move time (0x00 = instant,
 * 0x01..0x7F = 100 ms .. 12.7 s).
 *
 * PA0..PA3 are TIM2_CH1..CH4 and share a single time base. PWM wants 20 kHz,
 * a servo wants a 0.5..2.5 ms pulse every 20 ms (50 Hz), so the timer is
 * reconfigured whenever the active modes change: it runs at 20 kHz while only
 * GPIO/PWM pins are in use and at 50 Hz as soon as one servo is active. A PWM
 * record applied while a servo is active is still honoured as a duty
 * percentage, but at 50 Hz.
 *
 * Servo moves are interpolated in pins_tick() from the millisecond clock in
 * anim.c, so a move time produces a smooth sweep rather than a jump.
 */
#include <ch32x035.h>

#include "anim.h"
#include "pins.h"

#define PWM_PERIOD    (2399u)  /* 48 MHz / 2400 = 20 kHz */
#define SERVO_PSC     (47u)    /* 48 MHz / 48 = 1 MHz, so 1 tick = 1 us */
#define SERVO_PERIOD  (19999u) /* 20000 us = 20 ms = 50 Hz */
#define LEVEL_MAX     (0x7Fu)  /* 7-bit level: 0x00..0x7F = 0..100% */

/* Servo pulse range, configurable through pins_set_servo_range(). Values are
 * in 20 us units so 0.5..2.5 ms fits in a 7-bit byte. */
#define SERVO_RANGE_STEP_US   (20u)
#define SERVO_RANGE_MIN_UNITS (25u)  /* 500 us */
#define SERVO_RANGE_MAX_UNITS (125u) /* 2500 us */

enum
{
    PIN_MODE_INPUT = 0,
    PIN_MODE_GPIO,
    PIN_MODE_PWM,
    PIN_MODE_SERVO,
};

enum
{
    TIMER_MODE_PWM = 0,
    TIMER_MODE_SERVO,
};

static const uint16_t pin_mask[PINS_ADDR_LAST - PINS_ADDR_FIRST + 1] = {
    GPIO_Pin_0,
    GPIO_Pin_1,
    GPIO_Pin_2,
    GPIO_Pin_3,
};

typedef struct
{
    uint8_t mode;
    uint8_t duty;    /* last PWM level, kept so it survives a timer switch */
    uint8_t current; /* servo position currently driven */
    uint8_t target;  /* servo position being moved to */
    uint8_t start;   /* servo position the current move started from */
    uint32_t move_start_ms;
    uint32_t move_ms; /* 0 = jump straight to the target */
} pin_state_t;

static pin_state_t pin_state[PINS_ADDR_LAST - PINS_ADDR_FIRST + 1];
static uint8_t timer_mode = TIMER_MODE_PWM;
static uint8_t servo_count = 0;
static uint8_t timer_ready = 0;
static uint32_t servo_min_us = SERVO_RANGE_MIN_UNITS * SERVO_RANGE_STEP_US;
static uint32_t servo_max_us = SERVO_RANGE_MAX_UNITS * SERVO_RANGE_STEP_US;

static void write_ccr(uint8_t index, uint32_t ccr)
{
    switch (index)
    {
        case 0: TIM2->CH1CVR = (uint16_t)ccr; break;
        case 1: TIM2->CH2CVR = (uint16_t)ccr; break;
        case 2: TIM2->CH3CVR = (uint16_t)ccr; break;
        default: TIM2->CH4CVR = (uint16_t)ccr; break;
    }
}

static uint32_t timer_period(void)
{
    return timer_mode == TIMER_MODE_SERVO ? SERVO_PERIOD : PWM_PERIOD;
}

static void set_duty(uint8_t index, uint8_t level)
{
    pin_state[index].duty = level;
    write_ccr(index, (uint32_t)level * (timer_period() + 1) / LEVEL_MAX);
}

static void set_servo_pulse(uint8_t index, uint8_t position)
{
    uint32_t span = servo_max_us - servo_min_us;
    write_ccr(index, servo_min_us + (uint32_t)position * span / LEVEL_MAX);
}

/* Re-apply every active output for the current time base. */
static void reapply_outputs(void)
{
    for (uint8_t i = 0; i < PINS_ADDR_LAST - PINS_ADDR_FIRST + 1; i++)
    {
        if (pin_state[i].mode == PIN_MODE_PWM)
        {
            set_duty(i, pin_state[i].duty);
        }
        else if (pin_state[i].mode == PIN_MODE_SERVO)
        {
            set_servo_pulse(i, pin_state[i].current);
        }
    }
}

static void timer_config(uint8_t mode)
{
    TIM_TimeBaseInitTypeDef tb = {0};

    if (timer_mode == mode)
    {
        return;
    }
    timer_mode = mode;

    tb.TIM_Prescaler = (mode == TIMER_MODE_SERVO) ? SERVO_PSC : 0;
    tb.TIM_Period = (mode == TIMER_MODE_SERVO) ? SERVO_PERIOD : PWM_PERIOD;
    tb.TIM_ClockDivision = TIM_CKD_DIV1;
    tb.TIM_CounterMode = TIM_CounterMode_Up;
    tb.TIM_RepetitionCounter = 0;
    TIM_TimeBaseInit(TIM2, &tb); /* also reloads PSC/ARR immediately */

    reapply_outputs();
}
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

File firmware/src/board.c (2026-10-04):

/* Cylon hardware: 3 WS2812 LEDs on PB1
 *
 * LED: XL-4020RGBC-WS2812B (WS2812B compatible, data order G,R,B, MSB first)
 *   bit period : 1.25 us (800 kHz)
 *   '0' high   : ~0.33 us
 *   '1' high   : ~0.83 us
 *   reset low  : 125 us (100 bit periods)
 *
 * The waveform is generated with the TIM1 channel 3 complementary output
 * (TIM1_CH3N); TIM1 remap 001 routes it to PB1. TIM1 runs at 48 MHz
 * (prescaler 0, ARR = 59 -> 60 ticks = 1.25 us per bit) and DMA1 channel 5
 * (the TIM1_UP request) writes one compare value (CH3CVR) per timer update,
 * i.e. one value per WS2812 bit.
 *
 * CH3N is the complement of the PWM reference. With PWM mode 2 the reference
 * is low while CNT < CCR, so CH3N is high at the start of the period for CCR
 * ticks: the compare value is the bit's high time directly, and CCR = 0 keeps
 * the output low for the whole period (the reset/latch).
 */
#include <ch32x035.h> /* both X033 and X035 */
#include <string.h>   /* memset() */

#include "board.h"
#include "debug.h"

/* WS2812 data output: PB1 (TIM1_CH3N after TIM1 remap 001) */
#define LED_PORT GPIOB
#define LED_PIN  GPIO_Pin_1
#define LEDS_NUM BOARD_LEDS

/* bit timing in 48 MHz ticks */
#define BIT_PERIOD_TICKS (60)  /* 1.25 us */
#define BIT0_HIGH_TICKS  (16)  /* ~0.33 us */
#define BIT1_HIGH_TICKS  (40)  /* ~0.83 us */
#define RESET_ENTRIES    (100) /* 100 bit periods = 125 us */

#define LED_DMA_CH     DMA1_Channel5
#define CCR_BUFFER_LEN ((LEDS_NUM * 24) + RESET_ENTRIES)

typedef struct
{
    uint8_t g; /* Green */
    uint8_t r; /* Red */
    uint8_t b; /* Blue */
} ws2812b_color_t;

/* the LED colors as set by the caller */
static ws2812b_color_t leds[LEDS_NUM];

/* one compare value per WS2812 bit, plus the reset at the end of a frame */
static uint16_t ccr_buf[CCR_BUFFER_LEN];

/* encode one color byte as 8 compare values, MSB first */
static void encode_byte(uint16_t *buf, uint8_t value)
{
    for (int i = 0; i < 8; i++)
    {
        buf[i] = (value & (0x80 >> i)) ? BIT1_HIGH_TICKS : BIT0_HIGH_TICKS;
    }
}

/* encode one LED as 24 compare values in WS2812 order (G, R, B) */
static void encode_color(uint16_t *buf, uint8_t g, uint8_t r, uint8_t b)
{
    encode_byte(&buf[0], g);
    encode_byte(&buf[8], r);
    encode_byte(&buf[16], b);
}

/* configure TIM1_CH3N on PB1 for the WS2812 waveform */
static void led_timer_init(void)
{
    GPIO_InitTypeDef GPIO_InitStructure = {0};
    TIM_TimeBaseInitTypeDef TIM_TimeBaseStructure = {0};
    TIM_OCInitTypeDef TIM_OCInitStructure = {0};
    TIM_BDTRInitTypeDef TIM_BDTRInitStructure = {0};

    RCC_APB2PeriphClockCmd(RCC_APB2Periph_AFIO | RCC_APB2Periph_GPIOB | RCC_APB2Periph_TIM1, ENABLE);

    /* route TIM1_CH3N to PB1 */
    GPIO_PinRemapConfig(GPIO_PartialRemap1_TIM1, ENABLE);

    GPIO_InitStructure.GPIO_Pin = LED_PIN;
    GPIO_InitStructure.GPIO_Mode = GPIO_Mode_AF_PP;
    GPIO_InitStructure.GPIO_Speed = GPIO_Speed_50MHz;
    GPIO_Init(LED_PORT, &GPIO_InitStructure);

    TIM_TimeBaseStructure.TIM_Period = BIT_PERIOD_TICKS - 1;
    TIM_TimeBaseStructure.TIM_Prescaler = 0;
    TIM_TimeBaseStructure.TIM_ClockDivision = TIM_CKD_DIV1;
    TIM_TimeBaseStructure.TIM_CounterMode = TIM_CounterMode_Up;
    TIM_TimeBaseStructure.TIM_RepetitionCounter = 0;
    TIM_TimeBaseInit(TIM1, &TIM_TimeBaseStructure);

    TIM_OCInitStructure.TIM_OCMode = TIM_OCMode_PWM2;
    TIM_OCInitStructure.TIM_OutputState = TIM_OutputState_Enable;
    TIM_OCInitStructure.TIM_OutputNState = TIM_OutputNState_Enable;
    TIM_OCInitStructure.TIM_Pulse = 0;
    TIM_OCInitStructure.TIM_OCPolarity = TIM_OCPolarity_High;
    TIM_OCInitStructure.TIM_OCNPolarity = TIM_OCNPolarity_High;
    TIM_OCInitStructure.TIM_OCIdleState = TIM_OCIdleState_Reset;
    TIM_OCInitStructure.TIM_OCNIdleState = TIM_OCNIdleState_Reset;
    TIM_OC3Init(TIM1, &TIM_OCInitStructure);

    /* the dead-time/break block must be configured for the complementary
     * output to be driven (dead time 0, automatic output enable) */
    TIM_BDTRInitStructure.TIM_OSSIState = TIM_OSSIState_Disable;
    TIM_BDTRInitStructure.TIM_OSSRState = TIM_OSSRState_Disable;
    TIM_BDTRInitStructure.TIM_LOCKLevel = TIM_LOCKLevel_OFF;
    TIM_BDTRInitStructure.TIM_DeadTime = 0;
    TIM_BDTRInitStructure.TIM_Break = TIM_Break_Disable;
    TIM_BDTRInitStructure.TIM_BreakPolarity = TIM_BreakPolarity_High;
    TIM_BDTRInitStructure.TIM_AutomaticOutput = TIM_AutomaticOutput_Enable;
    TIM_BDTRConfig(TIM1, &TIM_BDTRInitStructure);

    /* shadow register on: each DMA value becomes active at the NEXT update
     * event, i.e. it is loaded a full bit period ahead of when it is used.
     * The frame therefore starts with one extra reset bit, and the first data
     * bit is transferred by the timer hardware at the update event rather than
     * by the DMA a few cycles late. */
    TIM_OC3PreloadConfig(TIM1, TIM_OCPreload_Enable);
    TIM_CCxNCmd(TIM1, TIM_Channel_3, TIM_CCxN_Enable);
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

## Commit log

2026-10-04 Add hardware
    [3D.step, BOM.csv, PickAndPlace.xlsx]
2026-10-04 Add servo support
2026-10-05 Add case
    [cover.scad, cover.stl]
